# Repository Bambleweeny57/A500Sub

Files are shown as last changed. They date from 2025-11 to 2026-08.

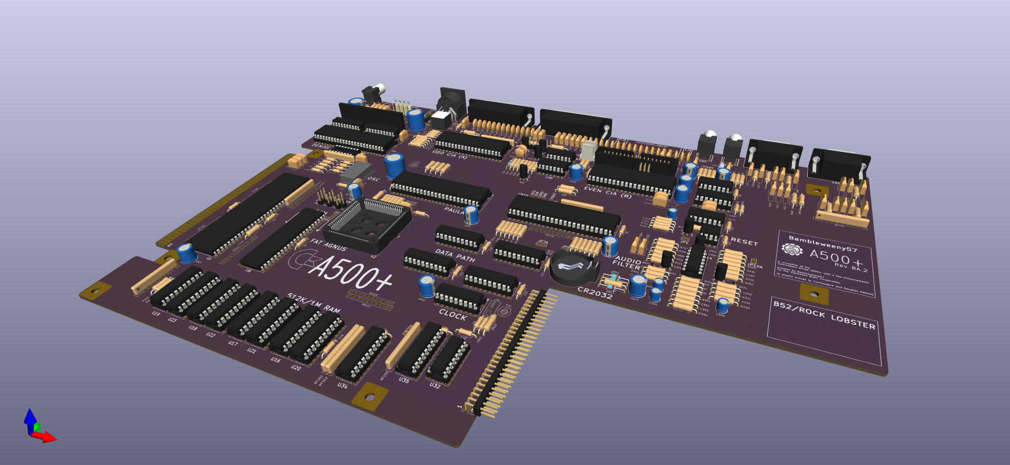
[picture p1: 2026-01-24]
images/Amiga500 3D Top.png

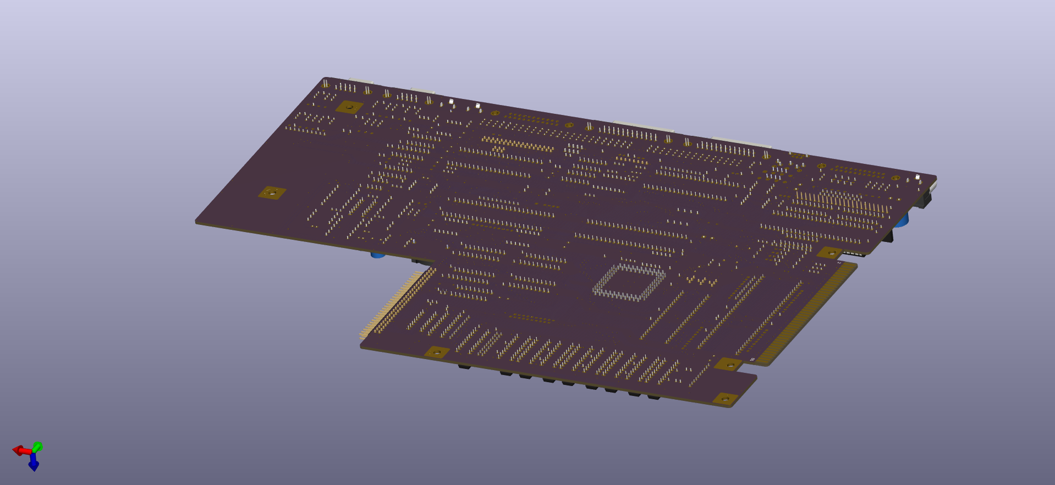
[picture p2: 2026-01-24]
images/Amiga500 3D Bottom.png

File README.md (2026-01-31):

# **A500Sub — Amiga A500+ Rev 8A.2 (KiCad Reconstruction)**

A full KiCad reconstruction of the **Commodore Amiga A500+ Rev 8A.2** motherboard, supported with a complete BOM, 3D models, and reference images.  
This project preserves the A500+ Rev 8A.2 board layout in an editable, open format for restoration, repair, and hardware exploration.

---

## 🧭 Project Purpose

The goal of this repository is to provide a clean, accurate, and reproducible version of the **A500+ Rev 8A.2** motherboard for:

- Restoring original A500+ systems  
- Building new boards from scratch  
- Hardware repair and diagnostics  
- Long‑term preservation of Commodore’s design  
- Modding, expansion, and experimentation  

All Gerbers and KiCad sources are included for manufacturing and study.

---

## 📁 Repository Structure

| Folder / File | Description |
|---|---|
| **`/src`** | Full KiCad project for the A500+ Rev 8A.2 board |
| **`/gerbers`** | Ready‑to‑manufacture Gerber set |
| **`/bom`** | Bill of Materials for component sourcing |
| **`/images`** | Board renders, 3D views, and reference images |
| **`Submeson A500+ gerbers.zip`** | Packaged Gerber archive for PCB fabrication |

---

## 🛠️ Features

### **✔️ Complete KiCad Reconstruction**
- Editable PCB layout  
- Accurate trace routing  
- Includes footprints, netlist, and 3D models  
- Suitable for fabrication without modification  

### **✔️ Manufacturing‑Ready Gerbers**
- Clean, validated Gerber set  
- Provided both in the `/gerbers` folder and as a ZIP archive  

### **✔️ Full BOM Included**
- Component list for building the board  
- Helps with sourcing legacy and modern‑equivalent parts  

### **✔️ 3D Models & Renders**
- Visual reference for assembly  
- Useful for verifying component placement and clearances  

---

## 🧩 About the Amiga A500+ Rev 8A.2

The **A500+** was the final revision of the classic Amiga 500 line, featuring:

- ECS chipset  
- 1 MB Chip RAM  
- Battery‑backed RTC  
- Updated motherboard layout  
- Improved memory and expansion handling  

Rev 8A.2 is one of the later, more stable board revisions, making it ideal for restoration and reproduction.

---

## 🚀 How to Use This Project

### **Open in KiCad**
```bash
git clone https://github.com/Bambleweeny57/A500Sub
```
Open

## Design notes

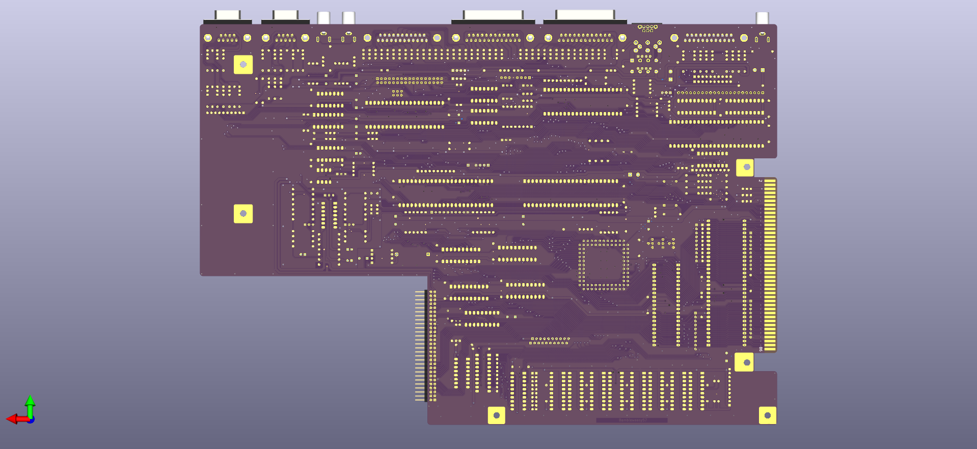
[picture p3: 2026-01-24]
images/Amiga500 3D Bottom Flat.png

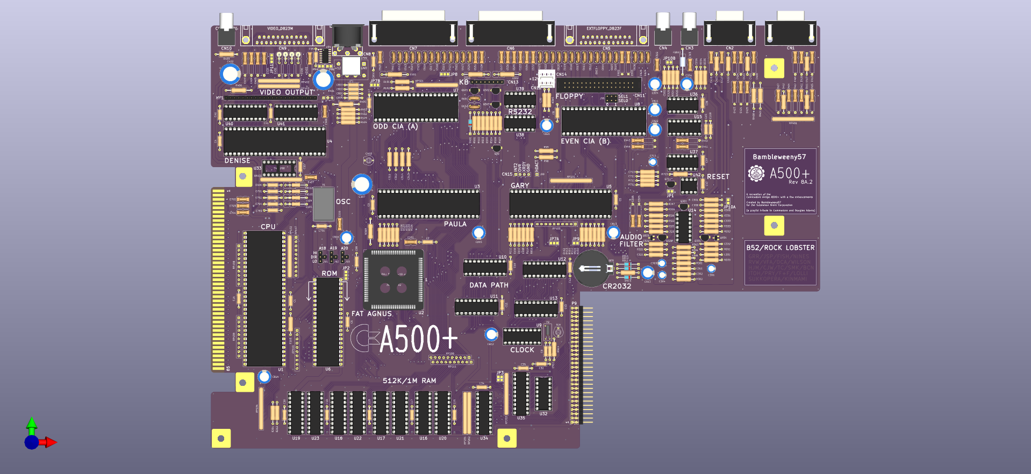
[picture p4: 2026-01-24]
images/Amiga500 3D Top Flat.png

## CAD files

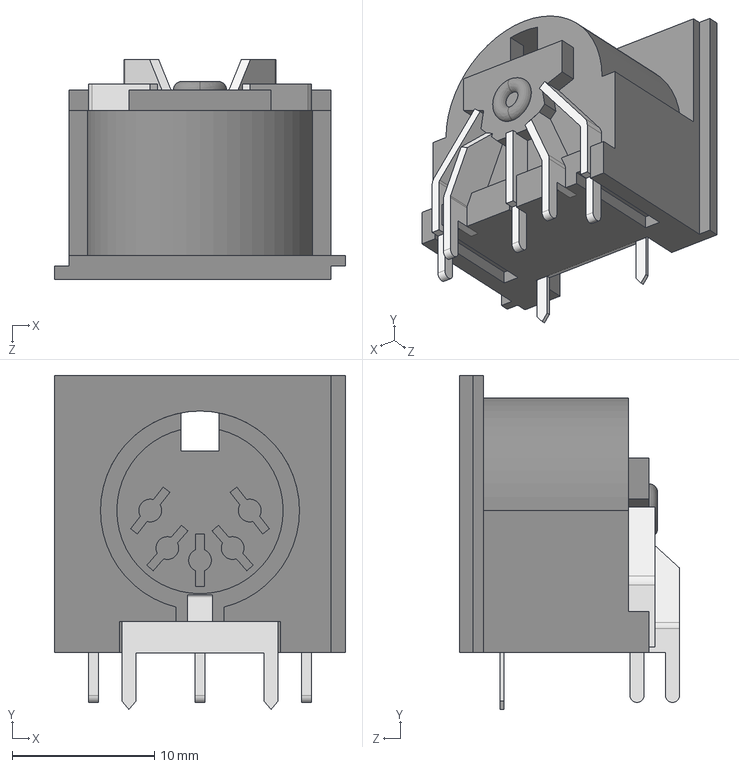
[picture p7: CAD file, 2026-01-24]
src/3dModels/KCDX-5S-N.stp
20.5 x 23.5 x 15.5 mm

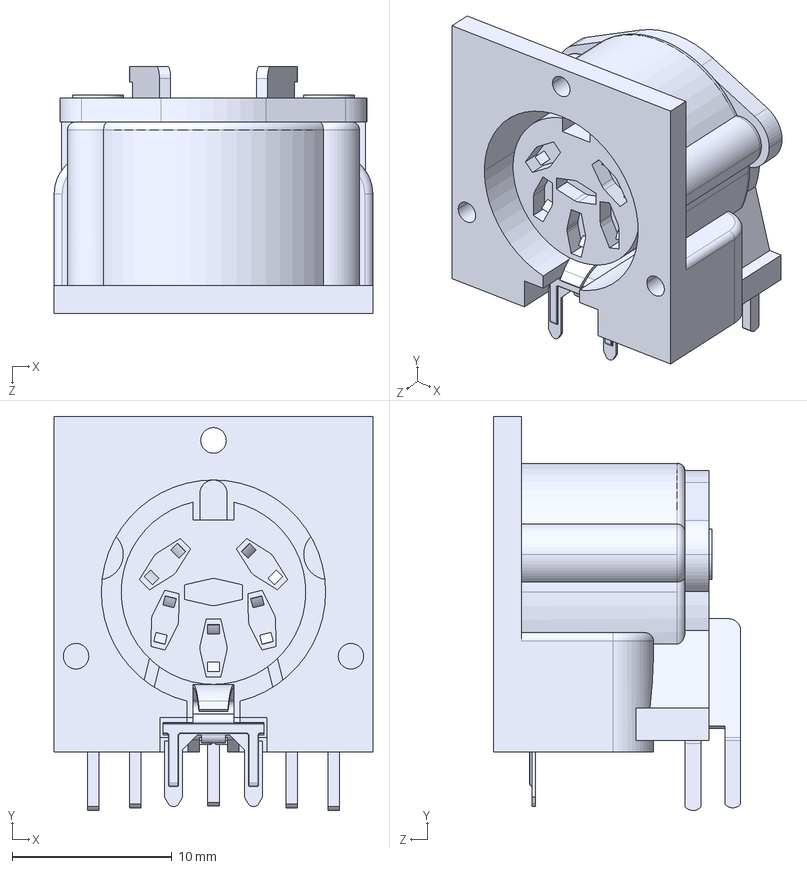
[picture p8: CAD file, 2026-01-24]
src/3dModels/61PC5F--3DModel-STEP-1.STEP
20.0 x 24.7 x 15.5 mm

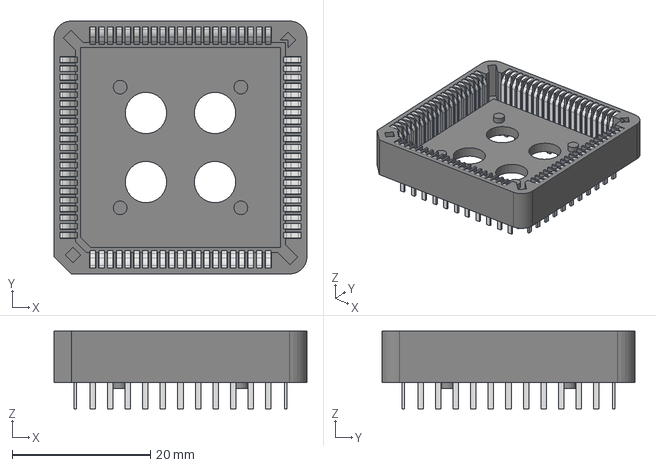
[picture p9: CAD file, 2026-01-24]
src/3dModels/PLCC-84-AT.stp
36.7 x 36.7 x 11.3 mm

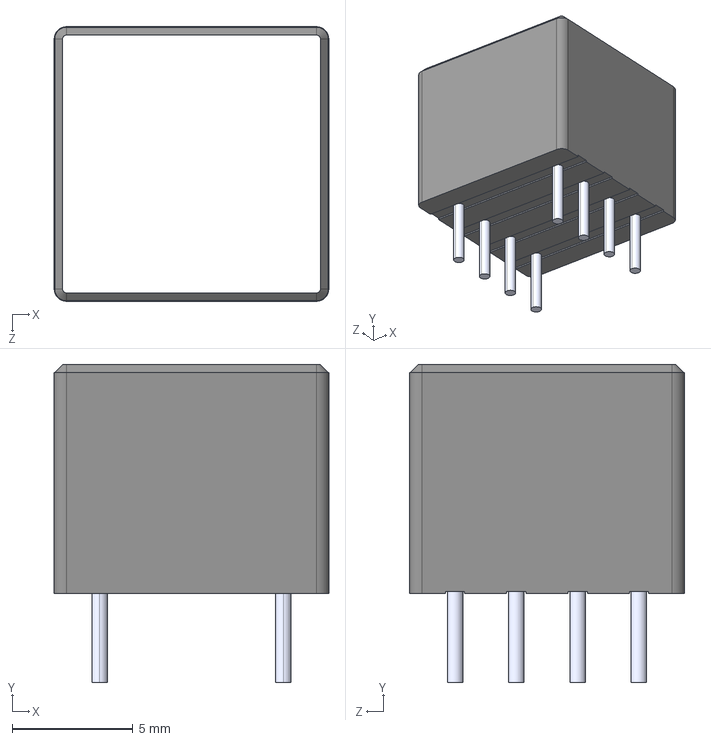
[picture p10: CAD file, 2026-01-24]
src/3dModels/CM4545Z131B-10--3DModel-STEP-460648.STEP
11.4 x 13.2 x 11.4 mm

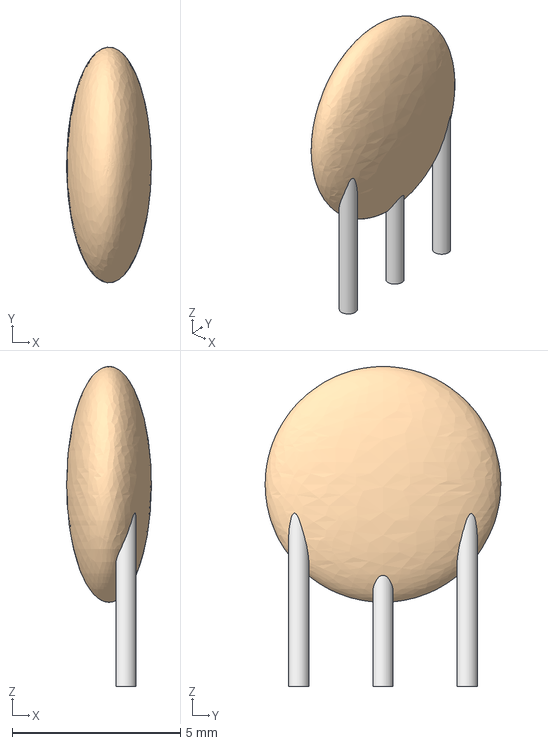
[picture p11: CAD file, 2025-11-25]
src/3dModels/DSN6.step
2.52 x 6.99 x 9.50 mm

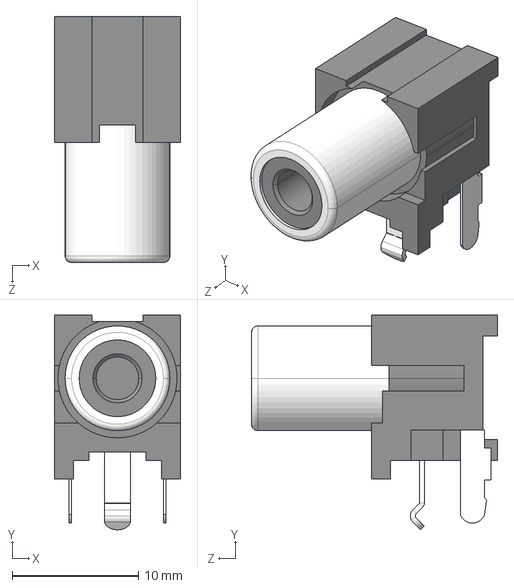
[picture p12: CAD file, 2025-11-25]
src/3dModels/PJRAN1X1U01X--3DModel-STEP-56544.stp
10.0 x 17.0 x 19.5 mm

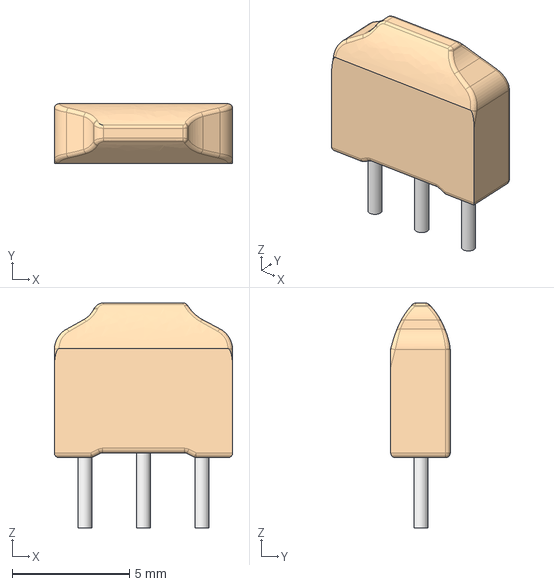
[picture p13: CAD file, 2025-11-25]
src/3dModels/DSS6.step
7.60 x 2.54 x 9.59 mm

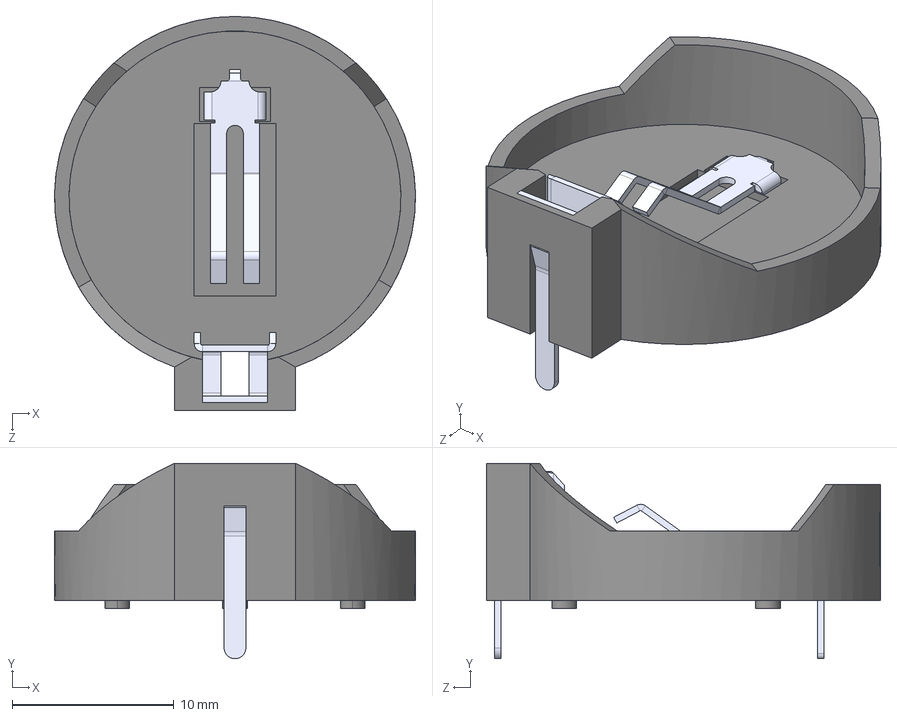
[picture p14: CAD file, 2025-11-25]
src/3dModels/BS-7.STEP
22.3 x 12.1 x 24.4 mm

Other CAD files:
src/3dModels/DSN6.FCStd
src/3dModels/DSS6.FCStd

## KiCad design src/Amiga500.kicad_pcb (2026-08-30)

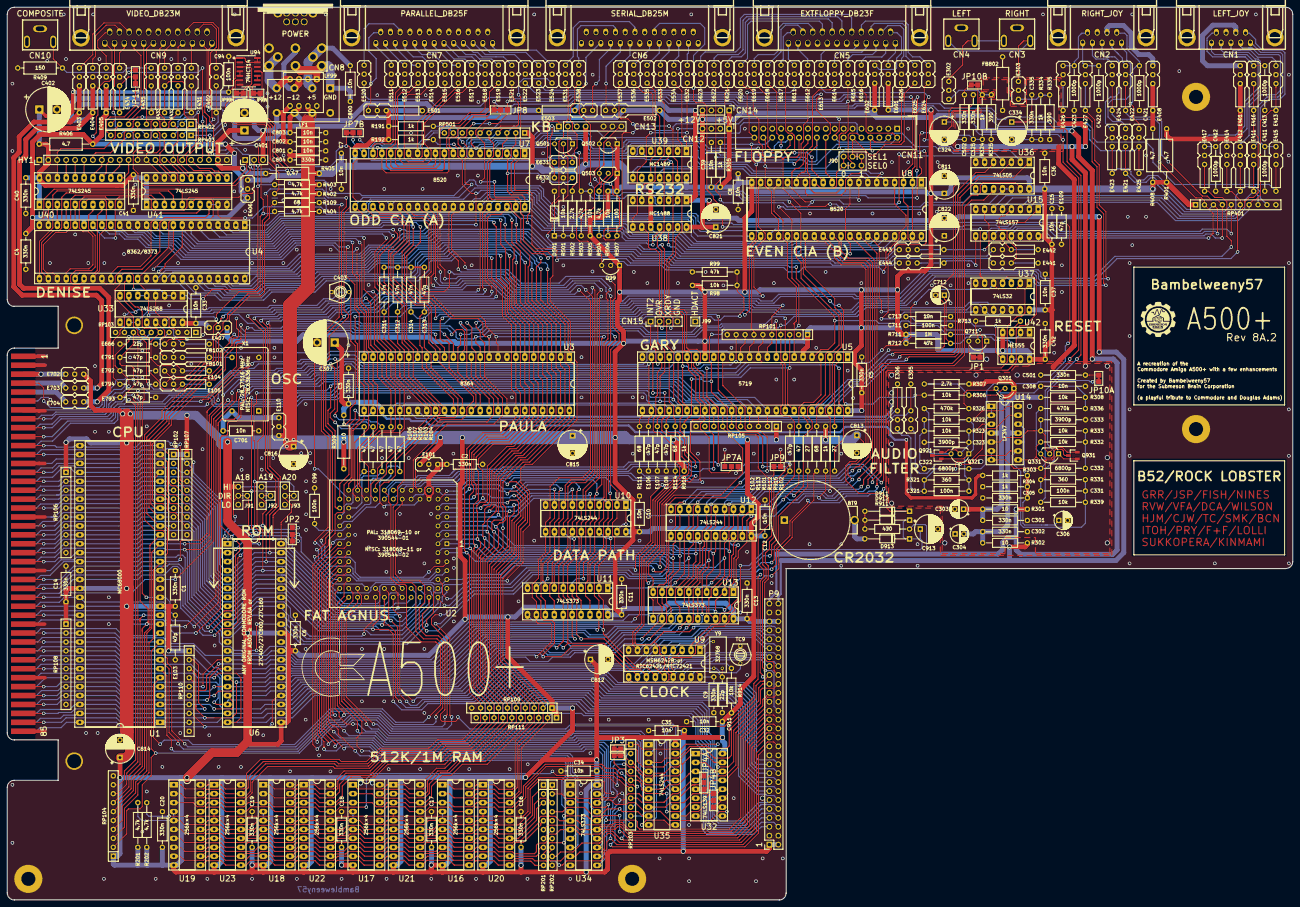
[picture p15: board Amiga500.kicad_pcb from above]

Board: 2 copper layers, 365.8 x 254.0 mm, 365 parts (0 on the bottom side), 471 nets.

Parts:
BT9: CR2032; Battery_Holder_Coin_2032_BS-7
C1, C2, C3, C4, C5, C6, C9, C11, C13, C14, C16, C17, C18, C19, C20, C40, C41, C42, C804: 330n; C_Axial_L6.3mm_D2.5mm_P10.16mm
C7, C8, C10, C12, C15, C32, C33, C34, C35, C36, C37, C701, C800, C801, C802, C803: 10n; C_Axial_L6.3mm_D2.5mm_P10.16mm
C39, C308, C713: 10n; C_Axial_L9.0mm_D3.2mm_P12.70mm
C94, C99: 100n; C_Axial_L6.3mm_D2.5mm_P10.16mm
C301, C302, C305, C325, C335, C501, C502: 330n; C_Axial_L9.0mm_D3.2mm_P12.70mm
C303, C304: 22u; CP_Radial_D5.0mm_P2.50mm
C306, C712: 10u; CP_Radial_D5.0mm_P2.50mm
C307, C401, C402: 1000u; CP_Radial_D12.5mm_P5.00mm
C311, C312, C313, C314: 47n; C_Axial_L9.0mm_D3.2mm_P12.70mm
C321, C331, C711: 100n; C_Axial_L9.0mm_D3.2mm_P12.70mm
C322, C332: 6800p; C_Axial_L9.0mm_D3.2mm_P12.70mm
C323, C333: 3900p; C_Axial_L9.0mm_D3.2mm_P12.70mm
C324, C334: 22u; CP_Radial_D8.0mm_P5.00mm
C403: 47p; VariCap
C411, C412, C413, C421, C422, C423: 1000p; C_Axial_L9.0mm_D3.2mm_P12.70mm
C811, C812, C813, C814, C815, C816: 100u; CP_Radial_D8.0mm_P5.00mm
C821, C822: 47u; CP_Radial_D8.0mm_P5.00mm
C911: 22p; C_Axial_L6.3mm_D2.5mm_P10.16mm
C913: 4.7u; CP_Radial_D8.0mm_P5.00mm
CN1: LEFT_JOY; DB_9M
CN2: RIGHT_JOY; DB_9M
CN3: RIGHT; SWITCHCRAFT_PJRAN1X1U01X
CN4: LEFT; SWITCHCRAFT_PJRAN1X1U01X
CN5: EXTFLOPPY_DB23F; DB_23F
CN6: SERIAL_DB25M; DB_25M
CN7: PARALLEL_DB25F; DB_25F
CN8: POWER; DS215+DIN8_COMBO
CN9: VIDEO_DB23M; DB_23M
CN10: COMPOSITE; SWITCHCRAFT_PJRAN1X1U01X
CN11: INTERNAL_FLOPPY; IDC-Header_2x17_P2.54mm_Vertical
CN12: FLOPPY_POWER; PinHeader_1x04_P2.54mm_Vertical
CN13: KEYBOARD; Keyboard_Connector
CN14: IDE_POWER; PinHeader_1x04_P2.54mm_Vertical
CN15: IDE_I/F; PinHeader_1x04_P2.54mm_Vertical
D501: 1N4148; D_DO-35_SOD27_P12.70mm_Horizontal
D911, D912, D913: 1n4148; D_DO-35_SOD27_P12.70mm_Horizontal
E101, E110, E406, E407, E702, E703, E704: 10n; EMI_Filter_Short
E102, E103, E106, E107, E108: 47p; C_Axial_L9.0mm_D3.2mm_P12.70mm
E104, E105: 68; EMI_Filter_Long
E109, E791, E792, E793, E794: 47p; C_Axial_L6.3mm_D2.5mm_P10.16mm
E302, E303: 6800p; EMI_Filter_Short
E305, E306: 270p; EMI_Filter_Long
E401, E403, E404, E405, E408, E601, E602: 10n; EMI_Filter_Long
E402, E434: 150p; EMI_Filter_Long
E411, E412, E413, E414, E421, E422, E423, E424: 6800p; EMI_Filter_Long
E415, E416, E417, E425, E426, E427, E441, E442, E443, E444: 470p; EMI_Filter_Long
E431, E432, E433, E435: FERR; EMI_Filter_Long
E501, E502, E503: 47 1/2W; EMI_Filter_Longer
E511, E512, E513, E514, E515, E516, E517, E518, E519, E521, E522, E523, E524, E611, E612, E613, E614, E615, E616, E617, E618, E619, E620, E621, E622, E623, E624, E625, E626, E631, E632: 100p; EMI_Filter_Short
E520, E531, E533, E535, E536, E537, E538: 470p; EMI_Filter_Short
E532, E534: 150p; EMI_Filter_Short
E666: 22p; C_Axial_L6.3mm_D2.5mm_P10.16mm
FB101: 68; EMI_Filter_Long
FB102: 150; EMI_Filter_Long
FB802: Ferrite_Bead_Small; Ferrite_Axial_L9.0mm_D3.2mm_P12.70mm
HY1: VIDIOT; PinHeader_1x22_P2.54mm_Vertical
HY2: COLOR_ANNEX; PinHeader_1x03_P2.54mm_Vertical
J90: DRIVE_SWITCHER; DriveSwitchHeader
J91, J92, J93: Dispatcher_3to1
J99: CONN_HDACT; PinHeader_1x01_P2.54mm_Vertical
JP1, JP3A1, JP3B1, JP10A1, JP10B1, JP99H1, JP99V1: Jumper_2_Bridged; Jumper2-Bridged
JP2, JP7B1, JP8: Jumper_3_Bridged23; Jumper3-Bridged23
JP4A1, JP4B1, JP7A1: Jumper_3_Open; Jumper3-Open
JP9: Jumper_2_Open; Jumper2-Open
JP11: Jumper_3_Bridged12; Jumper3-Bridged12
LF1: L; LineFilter
LF99: CM4545Z131B-10
MT1, MT2, MT4, MT5, MT6, MT7: MountingHole_Pad; MountingHole_4mm_Pad
P1: EXPANSION BUS; A2000_COPRO_SLOT
P9: TRAPDOOR; Trapdoor
Q99, Q301, Q502, Q503: 2N3906; TO-92L_Inline_Wide
Q321, Q331: MPF102; TO-92L_Inline_Wide
Q501, Q711: 2N3904; TO-92L_Inline_Wide
Q921, Q931: MMBFJ113; SOT-23_LongerPads
R98, R306, R308, R322, R323, R332, R333, R339, R501, R505, R506, R914: 10k; R_Axial_DIN0309_L9.0mm_D3.2mm_P12.70mm_Horizontal
R99, R712: 47k; R_Axial_DIN0309_L9.0mm_D3.2mm_P12.70mm_Horizontal
R101, R102: 27; R_Axial_DIN0309_L9.0mm_D3.2mm_P12.70mm_Horizontal
R103, R104, R105, R106, R107, R113: 47; R_Axial_DIN0309_L9.0mm_D3.2mm_P12.70mm_Horizontal
R109, R111, R112, R114: 68; R_Axial_DIN0309_L9.0mm_D3.2mm_P12.70mm_Horizontal
R191, R192, R303, R304, R305, R324, R334, R713, R915, R916: 1k; R_Axial_DIN0309_L9.0mm_D3.2mm_P12.70mm_Horizontal
R201, R202, R402, R403, R404, R503, R504: 4.7k; R_Axial_DIN0309_L9.0mm_D3.2mm_P12.70mm_Horizontal
R301, R302: 10; R_Axial_DIN0309_L9.0mm_D3.2mm_P12.70mm_Horizontal
R307, R502: 2.7k; R_Axial_DIN0309_L9.0mm_D3.2mm_P12.70mm_Horizontal
R309: 10; R_Axial_DIN0309_L9.0mm_D3.2mm_P15.24mm_Horizontal
R321, R331: 360; R_Axial_DIN0309_L9.0mm_D3.2mm_P12.70mm_Horizontal
R325, R335: 390; R_Axial_DIN0309_L9.0mm_D3.2mm_P12.70mm_Horizontal
R326, R336: 470k; R_Axial_DIN0309_L9.0mm_D3.2mm_P12.70mm_Horizontal
R401, R406, R408: 4.7; R_Axial_DIN0309_L9.0mm_D3.2mm_P15.24mm_Horizontal
R405: 0.47; R_Axial_DIN0309_L9.0mm_D3.2mm_P15.24mm_Horizontal
R409: 150; R_Axial_DIN0309_L9.0mm_D3.2mm_P12.70mm_Horizontal
R507: 100; R_Axial_DIN0309_L9.0mm_D3.2mm_P12.70mm_Horizontal
R711: 1M; R_Axial_DIN0309_L9.0mm_D3.2mm_P12.70mm_Horizontal
R911: 470; R_Axial_DIN0309_L9.0mm_D3.2mm_P12.70mm_Horizontal
RP101, RP102, RP105, RP106, RP107, RP108, RP109, RP110, RP111: 4.7k; R_Array_SIP10
RP103: 39; R_Array_SIP10
RP104: 470; R_Array_SIP10
RP201, RP202, RP203: 68; R_Array_SIP10
RP401: 4.7K; R_Array_SIP10
RP402, RP403: 47; R_Array_SIP10
RP501: 10k; R_Array_SIP10
TC9: 6.8-45p; VariCap
U1: 68000D; DIP-64_W22.86mm_Socket_LongPads
U2: FAT_AGNUS_8375; PLCC-84_THT-Socket
U3: PAULA; DIP-48_W15.24mm_Socket_LongPads
U4: DENISE; DIP-48_W15.24mm_Socket_LongPads
U5: GARY_5719; DIP-48_W15.24mm_Socket_LongPads
U6: ROM; DIP-42_W15.24mm_Socket_LongPads
U7, U8: VIA_8520; DIP-40_W15.24mm_Socket_LongPads
U9: MSM6242B; DIP-18_W7.62mm_Socket_LongPads
U10, U12, U35: 74LS244; DIP-20_W7.62mm_Socket_LongPads
U11, U13, U34: 74LS373; DIP-20_W7.62mm_Socket_LongPads
U14: LF347; DIP-14_W7.62mm_Socket_LongPads
U15: 74LS157; DIP-16_W7.62mm_Socket_LongPads
U16, U17, U18, U19, U20, U21, U22, U23: XX4256; DIP-20_W7.62mm_Socket_LongPads
U32: 74LS139; DIP-16_W7.62mm_Socket_LongPads
U33: 74LS258; DIP-16_W7.62mm_Socket_LongPads
U36: 74LS05; DIP-14_W7.62mm_Socket_LongPads
U37: 74LS32; DIP-14_W7.62mm_Socket_LongPads
U38: MC1488; DIP-14_W7.62mm_Socket_LongPads
U39: MC1489; DIP-14_W7.62mm_Socket_LongPads
U40, U41: 74LS245; DIP-20_W7.62mm_Socket_LongPads
U42: NE555; DIP-8_W7.62mm_Socket_LongPads
U94: 74HCT14; SOIC-14_3.9x8.7mm_P1.27mm
X1: XTAL; Oscillator_DIP-14
Y9: 32768; Crystal_RTC

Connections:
7MHZ: E103.1, P1.7, R106.1, U1.15
7MHZ_A: C403.1, E794.1, R107.1, U4.35
+12V: C802.1, C821.1, CN12.4, CN14.4, E404.1, E502.1, E602.1, E704.1, HY2.3, LF1.5, LF99.5, P9.55, R301.1, R911.2, U38.14
+VDC: C301.1, C303.1, Q301.1, R301.2, R307.2, U14.4
-12V: C803.2, C822.2, E403.1, E503.1, E703.1, LF1.6, LF99.6, P9.56, R302.2, U38.1
-VDC: C302.2, C304.2, R302.1, R308.2, U14.11
/Denise & Video Stuff/ab: E433.1, HY1.17
/Denise & Video Stuff/ag: E432.1, HY1.12
/Denise & Video Stuff/ar: E431.1, HY1.7
/Denise & Video Stuff/bb0: HY1.16, RP402.3, U41.15
/Denise & Video Stuff/bb1: HY1.15, U41.16
/Denise & Video Stuff/bb2: HY1.14, U41.17
/Denise & Video Stuff/bb3: HY1.13, RP402.5, U41.18
/Denise & Video Stuff/bcck: HY2.1, RP403.4, U41.14
/Denise & Video Stuff/bcsync_a: RP403.9, U41.12
/Denise & Video Stuff/bcsync_b: HY1.18, U41.11
/Denise & Video Stuff/bg0: HY1.11, U40.11
/Denise & Video Stuff/bg1: HY1.10, U40.12
/Denise & Video Stuff/bg2: HY1.9, U40.13
/Denise & Video Stuff/bg3: HY1.8, RP402.7, U40.14
/Denise & Video Stuff/bpixelsw: RP402.1, U41.13
/Denise & Video Stuff/br0: HY1.6, U40.15
/Denise & Video Stuff/br1: HY1.5, U40.16
/Denise & Video Stuff/br2: HY1.4, U40.17
/Denise & Video Stuff/br3: HY1.3, RP402.9, U40.18
/Denise & Video Stuff/cck_c: E402.1, RP403.3
/Denise & Video Stuff/csync_out: E434.1, JP11.2
/Denise & Video Stuff/hsync_buf: JP99H1.2, RP403.5, U94.6
/Denise & Video Stuff/rbcsync_a: JP11.1, RP403.10
/Denise & Video Stuff/vsync_buf: JP99V1.2, RP403.7, U94.8
/Kickstart ROM/a18_rom: J91.4, U6.2
/Kickstart ROM/a19_rom: J92.4, U6.1
/Kickstart ROM/a20_rom: J93.4, U6.42
/Parallel & Serial/+v: CN6.9, E502.3
/Parallel & Serial/-v: CN6.10, E503.3
/Parallel & Serial/cd: CN6.8, E537.3
/Parallel & Serial/clock: CN13.1, E632.1
/Parallel & Serial/cts: CN6.5, E535.3
/Parallel & Serial/data: CN13.2, E631.1
/Parallel & Serial/dsr: CN6.6, E536.3
/Parallel & Serial/dtr: CN6.20, E531.3
/Parallel & Serial/inuse: CN13.8, Q99.3, Q503.3
/Parallel & Serial/pp0: E512.1, U7.10
/Parallel & Serial/pp1: E513.1, U7.11
/Parallel & Serial/pp2: E514.1, U7.12
/Parallel & Serial/pp3: E515.1, U7.13
/Parallel & Serial/pp4: E516.1, U7.14
/Parallel & Serial/pp5: E517.1, U7.15
/Parallel & Serial/pp6: E518.1, U7.16
/Parallel & Serial/pp7: E519.1, U7.17
/Parallel & Serial/rts: CN6.4, E533.3
/Parallel & Serial/rxd: CN6.3, E534.3
/Parallel & Serial/sel0_out: J90.1, J90.2, U8.13
/Parallel & Serial/sel1_out: J90.5, J90.6, U8.14
/Parallel & Serial/status: CN13.7, Q502.3, R507.1
/Parallel & Serial/txd: CN6.2, E532.3
/Parallel & Serial/~auto: CN7.14, E501.3
/Parallel & Serial/~init: CN7.16, E520.3
/Paula & Audio Stuff/down1: CN1.2, E412.3
/Paula & Audio Stuff/down2: CN2.2, E422.3
/Paula & Audio Stuff/fire1: C411.1, CN1.6, E415.3
/Paula & Audio Stuff/fire2: C421.1, CN2.6, E425.3
/Paula & Audio Stuff/left: E306.1, U3.31
/Paula & Audio Stuff/left1: CN1.3, E413.3
/Paula & Audio Stuff/left2: CN2.3, E423.3
/Paula & Audio Stuff/pot0x: C311.1, E417.1, U3.32
/Paula & Audio Stuff/pot0y: C312.1, E416.1, U3.33
/Paula & Audio Stuff/pot1x: C313.1, E427.1, U3.35
/Paula & Audio Stuff/pot1y: C314.1, E426.1, U3.36
/Paula & Audio Stuff/potx1: C412.1, CN1.5, E417.3
/Paula & Audio Stuff/potx2: C422.1, CN2.5, E427.3
/Paula & Audio Stuff/poty1: C413.1, CN1.9, E416.3
/Paula & Audio Stuff/poty2: C423.1, CN2.9, E426.3
/Paula & Audio Stuff/right: E305.1, U3.30
/Paula & Audio Stuff/right1: CN1.4, E414.3
/Paula & Audio Stuff/right2: CN2.4, E424.3
/Paula & Audio Stuff/up1: CN1.1, E411.3
/Paula & Audio Stuff/up2: CN2.1, E421.3
/Paula & Audio Stuff/vcc1: CN1.7, E401.3
/Paula & Audio Stuff/vcc2: CN2.7, E408.3
/RAM/ma0: RP202.3, U16.6, U17.6, U18.6, U19.6, U20.6, U21.6, U22.6, U23.6
/RAM/ma1: RP202.5, U16.7, U17.7, U18.7, U19.7, U20.7, U21.7, U22.7, U23.7
/RAM/ma2: RP202.7, U16.8, U17.8, U18.8, U19.8, U20.8, U21.8, U22.8, U23.8
/RAM/ma3: RP202.10, U16.9, U17.9, U18.9, U19.9, U20.9, U21.9, U22.9, U23.9
/RAM/ma4: RP201.10, U16.11, U17.11, U18.11, U19.11, U20.11, U21.11, U22.11, U23.11
/RAM/ma5: RP201.8, U16.12, U17.12, U18.12, U19.12, U20.12, U21.12, U22.12, U23.12
/RAM/ma6: RP201.5, U16.13, U17.13, U18.13, U19.13, U20.13, U21.13, U22.13, U23.13
/RAM/ma7: RP201.3, U16.14, U17.14, U18.14, U19.14, U20.14, U21.14, U22.14, U23.14
/RAM/ma8: RP202.1, U16.15, U17.15, U18.15, U19.15, U20.15, U21.15, U22.15, U23.15
/RAM/~bcasl0: JP4A1.1, RP203.7, U32.4
/RAM/~bcasu0: JP4B1.1, RP203.5, U32.12
A1: P1.29, RP107.9, U1.29, U2.60, U6.10
A2: P1.27, P9.45, RP107.8, U1.30, U2.61, U6.9, U9.4
A3: P1.26, P9.46, RP107.7, U1.31, U2.62, U6.8, U9.5
A4: P1.24, P9.47, RP107.6, U1.32, U2.63, U6.7, U9.6
A5: P1.21, P9.48, RP107.5, U1.33, U2.64, U6.6, U9.7
A6: P1.23, RP107.4, U1.34, U2.65, U6.5
A7: P1.28, RP107.2, U1.35, U2.66, U6.4
A8: P1.30, RP107.3, U1.36, U2.67, U6.3, U7.38, U8.38
A9: P1.32, RP106.2, U1.37, U2.68, U6.41, U7.37, U8.37
A10: P1.34, RP106.3, U1.38, U2.69, U6.40, U7.36, U8.36
A11: P1.36, RP106.4, U1.39, U2.70, U6.39, U7.35, U8.35
A12: P1.38, RP106.5, U1.40, U2.71, U6.38, U37.1
A13: P1.39, RP106.6, U1.41, U2.72, U6.37, U37.4
A14: P1.41, RP106.7, U1.42, U2.73, U6.36
A15: P1.43, RP106.8, U1.43, U2.74, U6.35, U36.13
A16: P1.45, RP106.9, U1.44, U2.75, U6.34
A17: P1.47, RP105.8, U1.45, U2.76, U5.33, U6.33
A18: J91.2, P1.52, RP105.7, U1.46, U2.77, U5.34
A19: J92.2, JP2.3, P1.54, RP105.6, U1.47, U5.35
A20: J93.2, P1.56, RP105.5, U1.48, U2.35, U5.36
A21: P1.58, RP105.4, U1.50, U5.37
A22: P1.57, RP105.3, U1.51, U5.38
A23: JP2.1, P1.59, RP105.2, U1.52, U5.39
AUDIN: C501.1, JP10A1.1
AUDOUT: C502.2, JP10B1.2
BDRA0: P9.23, RP202.4, U35.9
BDRA1: P9.24, RP202.6, U35.7
BDRA2: P9.25, RP202.8, U34.9
BDRA3: P9.26, RP202.9, U34.19
BDRA4: P9.27, RP201.9, U34.16
BDRA5: P9.28, RP201.7, U34.6
BDRA6: P9.29, RP201.6, U34.15
BDRA7: P9.30, RP201.4, U34.5
BDRA8: P9.31, RP202.2, U34.12
BDRA9: U32.2, U32.14, U34.2
CCK: E108.1, R103.1, U3.28, U4.36, U5.28, U33.5, U33.6, U35.15, U41.6
CCKQ: E107.1, R104.1, U3.29, U5.27, U33.10, U33.11
CDAC: E793.1, P1.15, RP103.4
D0: P1.75, P9.41, RP110.5, U1.5, U6.14, U7.33, U9.14, U10.2, U11.2
D1: P1.77, P9.42, RP110.6, U1.4, U6.16, U7.32, U9.13, U10.4, U11.5
D2: P1.79, P9.43, RP110.7, U1.3, U6.18, U7.31, U9.12, U10.6, U11.6
D3: P1.81, P9.44, RP110.8, U1.2, U6.20, U7.30, U9.11, U10.8, U11.9
D4: P1.83, RP110.9, U1.1, U6.23, U7.29, U10.11, U11.12
D5: P1.86, RP110.4, U1.64, U6.25, U7.28, U10.13, U11.15
D6: P1.84, RP110.3, U1.63, U6.27, U7.27, U10.15, U11.16
D7: P1.82, RP110.2, U1.62, U6.29, U7.26, U10.17, U11.19
D8: P1.80, RP108.9, U1.61, U6.15, U8.33, U12.2, U13.2
D9: P1.78, RP108.8, U1.60, U6.17, U8.32, U12.4, U13.5
D10: P1.76, RP108.7, U1.59, U6.19, U8.31, U12.6, U13.6
D11: P1.71, RP108.6, U1.58, U6.21, U8.30, U12.8, U13.9
D12: P1.69, RP108.5, U1.57, U6.24, U8.29, U12.11, U13.12
D13: P1.67, RP108.4, U1.56, U6.26, U8.28, U12.13, U13.15
D14: P1.65, RP108.3, U1.55, U6.28, U8.27, U12.15, U13.16
D15: P1.63, RP108.2, U1.54, U6.30, U8.26, U12.17, U13.19
DIR: CN11.18, E623.1, U8.11
DKWE: U3.39, U5.8
DMAL: U2.18, U3.12
DRA0: U2.42, U35.11
DRA1: U2.43, U35.13
DRA2: U2.44, U34.8
DRA3: U2.45, U34.18
DRA4: U2.46, U34.17
DRA5: U2.47, U34.7
DRA6: U2.48, U34.14
DRA7: U2.49, U34.4
DRA8: U2.50, U34.13
DRA9: U2.55, U34.3
DRD0: P9.5, RP111.2, U2.14, U3.10, U4.7, U10.18, U11.3, U16.18, U20.18
DRD1: P9.6, RP109.2, U2.13, U3.9, U4.6, U10.16, U11.4, U16.2, U20.2
DRD2: P9.7, RP111.3, U2.12, U3.7, U4.5, U10.14, U11.7, U16.19, U20.19
DRD3: P9.8, RP109.3, U2.11, U3.6, U4.4, U10.12, U11.8, U16.1, U20.1
DRD4: P9.9, RP111.4, U2.10, U3.5, U4.3, U10.9, U11.13, U17.18, U21.18
DRD5: P9.10, RP109.4, U2.9, U3.4, U4.2, U10.7, U11.14, U17.2, U21.2
DRD6: P9.11, RP111.5, U2.8, U3.3, U4.1, U10.5, U11.17, U17.19, U21.19
DRD7: P9.12, RP109.5, U2.7, U3.2, U4.48, U10.3, U11.18, U17.1, U21.1
DRD8: P9.13, RP111.6, U2.6, U3.1, U4.47, U12.18, U13.3, U18.18, U22.18
DRD9: P9.14, RP109.6, U2.5, U3.48, U4.46, U12.16, U13.4, U18.2, U22.2
DRD10: P9.15, RP111.7, U2.4, U3.47, U4.45, U12.14, U13.7, U18.19, U22.19
DRD11: P9.16, RP109.7, U2.3, U3.46, U4.44, U12.12, U13.8, U18.1, U22.1
DRD12: P9.17, RP111.8, U2.2, U3.45, U4.43, U12.9, U13.13, U19.18, U23.18
DRD13: P9.18, RP109.8, U2.1, U3.44, U4.42, U12.7, U13.14, U19.2, U23.2
DRD14: P9.19, RP111.9, U2.84, U3.43, U4.41, U12.5, U13.17, U19.19, U23.19
DRD15: P9.20, RP109.9, U2.83, U3.42, U4.40, U12.3, U13.18, U19.1, U23.1
E: P1.50, R109.2, U1.20
FC0: P1.31, RP102.4, U1.28
FC1: P1.33, RP102.5, U1.27
FC2: P1.35, RP102.6, U1.26
GND: BT9.2, C1.2, C2.2, C3.2, C4.2, C5.2, C6.2, C7.2, C8.2, C9.2, C10.2, C11.2, C12.2, C13.2, C14.2, C15.2, C16.2, C17.2, C18.2, C19.2, C20.2, C32.2, C33.2, C34.2, C35.2, C36.2, C37.2, C39.2, C40.2, C41.2, C42.2, C94.2, C99.2, C307.2, C401.2, C402.2, C403.2, C411.2, C412.2, C413.2, C421.2, C422.2, C423.2, C701.2, C711.2, C712.2, C713.2, C801.e, C802.2, C803.1, C804.2, C811.2, C812.2, C813.2, C814.2, C815.2, C816.2, C821.2, C822.1, C911.1, C913.2, CN1.0, CN1.8, CN2.0, CN2.8, CN3.1, CN4.1, CN5.0, CN5.3, CN5.4, CN5.5, CN5.6, CN5.7, CN6.0, CN6.7, CN7.0, CN7.17, CN7.18, CN7.19, CN7.20, CN7.21, CN7.22, CN7.23, CN7.24, CN7.25, CN8.2, CN8.6, CN9.0, CN9.13, CN9.16, CN9.17, CN9.18, CN9.19, CN9.20, CN10.1, CN11.1, CN11.5, CN11.7, CN11.9, CN11.11, CN11.13, CN11.15, CN11.17, CN11.19, CN11.21, CN11.23, CN11.25, CN11.27, CN11.29, CN11.31, CN11.33, CN12.2, CN12.3, CN13.6, CN14.2, CN14.3, CN15.4, D501.2, E101.2, E102.2, E103.2, E104.2, E105.2, E106.2, E107.2, E108.2, E109.2, E110.2, E302.2, E303.2, E401.2, E402.2, E403.2, E404.2, E405.2, E406.2, E407.2, E408.2, E411.2, E412.2, E413.2, E414.2, E415.2, E416.2, E417.2, E421.2, E422.2, E423.2, E424.2, E425.2, E426.2, E427.2, E431.2, E432.2, E433.2, E434.2, E435.2, E441.2, E442.2, E443.2, E444.2, E501.2, E502.2, E503.2, E511.2, E512.2, E513.2, E514.2, E515.2, E516.2, E517.2, E518.2, E519.2, E520.2, E521.2, E522.2, E523.2, E524.2, E531.2, E532.2, E533.2, E534.2, E535.2, E536.2, E537.2, E538.2, E601.2, E602.2, E611.2, E612.2, E613.2, E614.2, E615.2, E616.2, E617.2, E618.2, E619.2, E620.2, E621.2, E622.2, E623.2, E624.2, E625.2, E626.2, E631.2, E632.2, E666.2, E702.2, E703.2, E704.2, E791.2, E792.2, E793.2, E794.2, FB101.2, FB102.2, FB802.2, HY1.1, HY1.22, J91.3, J92.3, J93.3, JP7A1.1, JP9.1, LF1.8, LF99.8, MT1.1, MT2.1, MT4.1, MT5.1, MT6.1, MT7.1, P1.1, P1.2, P1.3, P1.4, P1.12, P1.13, P1.25, P1.37, P1.49, P1.61, P1.73, P1.85, P9.3, P9.4, P9.21, P9.22, P9.34, P9.53, P9.54, Q501.1, Q711.1, R409.2, R501.1, RP101.10, RP102.10, RP104.10, RP105.10, RP106.10, RP107.10, RP108.10, RP109.10, RP110.10, RP111.10, RP401.10, TC9.2, U1.16, U1.53, U2.41, U2.58, U2.82, U3.8, U4.37, U5.1, U5.24, U5.40, U6.11, U6.12, U6.31, U7.1, U8.1, U9.9, U10.10, U11.10, U12.10, U13.10, U15.8, U15.15, U16.16, U16.20, U17.16, U17.20, U18.16, U18.20, U19.16, U19.20, U20.16, U20.20, U21.16, U21.20, U22.16, U22.20, U23.16, U23.20, U32.8, U33.8, U33.15, U34.1, U34.10, U35.1, U35.10, U35.19, U36.7, U37.7, U37.10, U37.13, U38.7, U39.7, U40.10, U40.19, U41.10, U41.19, U42.1, U94.7, X1.1, X1.7
GNDA: C301.2, C302.1, C303.2, C304.1, C305.2, C306.2, C308.2, C311.2, C312.2, C313.2, C314.2, C323.2, C333.2, E305.2, E306.2, FB802.1, R304.1, R325.2, R335.2, U3.34
M0H: E443.3, U4.9
M0V: E441.3, U4.38
M1H: E442.3, U4.8
M1V: E444.3, U4.39
unnamed: BT9.1, D913.2
unnamed: C2.1, E101.3, U2.15
unnamed: C3.1, C307.1, R303.2, R309.2, U3.27
unnamed: C9.1, C913.1, D912.1, D913.1, U9.18
unnamed: C33.1, E407.3, U33.16
unnamed: C99.1, U2.40
unnamed: C308.1, Q301.3, R308.1, R326.2, R336.2
unnamed: C321.1, Q321.1, Q921.1, R321.1, R322.2, U14.14
unnamed: C321.2, E306.3, R321.2, U14.13
unnamed: C322.1, C324.1, C325.2, U14.1, U14.2
unnamed: C322.2, R322.1, R323.2
unnamed: C323.1, Q321.2, Q921.2, R323.1, U14.3
unnamed: C324.2, C325.1, JP10B1.1, R324.2
unnamed: C331.1, Q331.1, Q931.1, R331.1, R332.2, U14.8
unnamed: C331.2, E305.3, R331.2, R339.1, U14.9
unnamed: C332.1, C334.1, C335.2, U14.6, U14.7
unnamed: C332.2, R332.1, R333.2
unnamed: C333.1, Q331.2, Q931.2, R333.1, U14.5
unnamed: C334.2, C335.1, R334.2
unnamed: C401.1, HY1.21, R405.2
unnamed: C501.2, CN6.18
unnamed: C502.1, CN6.11
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

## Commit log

2025-11-25 Commit first A500Sub
    [Amiga500-B_Cu.gbr, Amiga500-B_Mask.gbr, Amiga500-B_Silkscreen.gbr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]
2025-11-25 created gerbers
    [Amiga500-B_Cu.gbr, Amiga500-B_Mask.gbr, Amiga500-B_Silkscreen.gbr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]
2026-01-06 updated rev 8A.2
    [Amiga500-B_Cu.gbr, Amiga500-B_Mask.gbr, Amiga500-B_Silkscreen.gbr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]
2026-01-24 Added 3D models
    [61PC5F--3DModel-STEP-1.STEP, Amiga500.kicad_pcb, Amiga500.kicad_sch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]
2026-01-24 Built new Gerber files
    [Amiga500-B_Cu.gbr, Amiga500-B_Mask.gbr, Amiga500-B_Silkscreen.gbr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]
2026-02-16 changed silkscreen thickness
    [Amiga500-B_Cu.gbr, Amiga500-B_Mask.gbr, Amiga500-B_Silkscreen.gbr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]
2026-08-30 kicad 10
    [Amiga500-B_Cu.gbr, Amiga500-B_Mask.gbr, Amiga500-B_Silkscreen.gbr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]
